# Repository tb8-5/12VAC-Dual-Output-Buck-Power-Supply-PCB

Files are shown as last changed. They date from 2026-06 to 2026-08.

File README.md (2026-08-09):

# 12VAC Dual-Output Buck Power Supply PCB

**Status:** Design Complete / Fabrication In Progress  
**Input:** 12 VAC RMS, 60 Hz  
**Outputs:** Fixed 5 V and 3.3 V rails  
**PCB:** 2-layer, 80.15 mm × 34.20 mm, 1.6 mm FR-4  
**Copper:** 35 µm top / 35 µm bottom  
**Revision:** Rev A  
**Design tools:** KiCad 9 and LTspice  

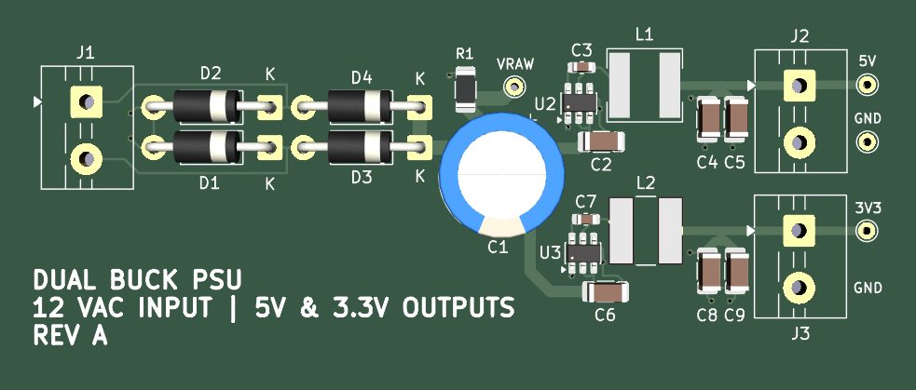
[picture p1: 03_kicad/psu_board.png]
3D render of the dual-output buck power supply PCB


## Overview

This project is a compact AC-to-DC power supply PCB that accepts **12 VAC** and produces two regulated DC outputs: **5 V** and **3.3 V**.

In simple terms, the board performs three jobs:

1. **Converts AC into DC** using a four-diode bridge rectifier.
2. **Smooths the rectified voltage** using a large bulk capacitor.
3. **Efficiently steps the DC voltage down** into separate 5 V and 3.3 V rails using two buck converters.

The project began with a linear-regulator architecture, but thermal calculations showed that too much power would be lost as heat. I redesigned the supply around two switching regulators and carried the design through schematic capture, component selection, footprint verification, PCB layout, routing, BOM preparation, and assembly-position-file generation.

The board has **not yet been fabricated or bench-tested**, so measured voltage, ripple, load-regulation, efficiency, and thermal results are intentionally left pending.

> **Input note:** This PCB is intended for a low-voltage 12 VAC source. It is not designed to connect directly to wall mains.

---

## Design Decision

### Original Linear-Regulator Approach

The first version used an **LM7805** to generate 5 V, followed by a second linear regulator for the 3.3 V rail.

LTspice rectifier simulation placed the filtered raw DC bus near **15.6 V**. At a 5 V, 1 A operating point, the LM7805 alone would dissipate:

```text
PLOSS = (VIN - VOUT) × IOUT

PLOSS = (15.6 V - 5 V) × 1 A
PLOSS = 10.6 W
```

A linear regulator removes excess voltage by turning it into heat. In this case, the regulator would be dissipating more than 10 W while only delivering 5 W to the load.

That made the linear architecture a poor fit for the size and thermal goals of the board.

### Buck-Converter Redesign

The supply was rebuilt around two fixed-output synchronous buck converters connected in parallel to the rectified DC bus:

- **U2 — AP63205WU-7:** fixed 5 V buck converter
- **U3 — AP63203WU-7:** fixed 3.3 V buck converter

A buck converter uses high-frequency switching, an inductor, and capacitors to transfer energy efficiently instead of continuously burning the voltage difference as heat.

The two output stages are **not cascaded**. Both converters receive power directly from `V_Raw`, so the 3.3 V rail does not depend on the 5 V regulator operating first.

---

## Final Architecture

```text
                         12 VAC INPUT
                              │
                              ▼
                 D1-D4: 1N4004 Bridge Rectifier
                              │
                              ▼
                 C1: 1000 µF Bulk Capacitor
                 R1: 10 kΩ Bleeder Resistor
                              │
                              ▼
                         V_RAW DC BUS
                              │
                 ┌────────────┴────────────┐
                 │                         │
                 ▼                         ▼
        5 V BUCK CONVERTER        3.3 V BUCK CONVERTER
            AP63205WU                 AP63203WU
                 │                         │
         C2: 10 µF input            C6: 10 µF input
         C3: 100 nF BST             C7: 100 nF BST
         L1: 4.7 µH                 L2: 3.9 µH
         C4/C5: 2 × 22 µF           C8/C9: 2 × 22 µF
                 │                         │
                 ▼                         ▼
           J2: 5 V / GND              J3: 3.3 V / GND
                 │                         │
             5 V test pad              3V3 test pad
```

Additional test access is provided for **VRAW** and **GND**.

---

## How the Circuit Works

### 1. AC Input and Full-Wave Rectification

`J1` accepts the 12 VAC input.

The four **1N4004** diodes (`D1-D4`) form a full-wave bridge rectifier. During each half-cycle of the AC waveform, a different pair of diodes conducts so that current through the DC side of the circuit always flows in the same direction.

For a 12 VAC RMS source, the unloaded sine-wave peak is approximately:

```text
VPEAK = VRMS × √2
VPEAK = 12 V × √2
VPEAK ≈ 16.97 V
```

The bridge introduces diode losses, so the usable rectified voltage is lower than the ideal peak. The LTspice work for this design produced a filtered raw bus near **15.6 V**.

Because both halves of the 60 Hz input waveform are used, the rectified ripple occurs at approximately **120 Hz**.

### 2. Bulk Filtering and VRAW

`C1` is a **1000 µF electrolytic capacitor** placed across the rectified output.

The bridge charges C1 near the peaks of the AC waveform. Between peaks, C1 supplies energy to the load and helps keep `V_Raw` from falling immediately back toward zero.

A first-order capacitor-ripple relationship is:

```text
ΔV ≈ ILOAD / (FRIPPLE × C)
```

where:

- `ΔV` is the approximate peak-to-peak bus ripple,
- `ILOAD` is the load current drawn from the rectified bus,
- `FRIPPLE` is approximately 120 Hz for 60 Hz full-wave rectification,
- `C` is the bulk capacitance.

`R1`, a **10 kΩ bleeder resistor**, provides a discharge path for the bulk capacitor after input power is removed. At approximately 15.6 V, it draws about **1.6 mA**, and the nominal `R × C` time constant is approximately **10 seconds**.

### 3. 5 V Buck Stage

The upper regulator stage uses `U2`, an **AP63205WU-7**, to generate the fixed 5 V rail.

Its external power-stage components are:

- `C2` — 10 µF local input capacitor
- `C3` — 100 nF bootstrap capacitor
- `L1` — 4.7 µH **TYS60284R7N-10**
- `C4`, `C5` — two 22 µF output capacitors

The switching node drives L1, and the inductor/output-capacitor network filters the switched waveform into a regulated DC output.

The finished 5 V rail is available at:

- `J2`
- the dedicated **5V** test pad

### 4. 3.3 V Buck Stage

The lower stage follows the same architecture using `U3`, an **AP63203WU-7**, for the fixed 3.3 V rail.

Its external components are:

- `C6` — 10 µF local input capacitor
- `C7` — 100 nF bootstrap capacitor
- `L2` — 3.9 µH **ASPI-0628-3R9M-T1**
- `C8`, `C9` — two 22 µF output capacitors

The finished 3.3 V rail is available at:

- `J3`
- the dedicated **3V3** test pad

---

## PCB Implementation

The final layout is a **2-layer board** measuring **80.15 mm × 34.20 mm**.

### Layer Stack

```text
Top Silkscreen
Top Solder Mask
35 µm F.Cu
1.51 mm FR-4 core
35 µm B.Cu
Bottom Solder Mask
Bottom Silkscreen
```

The complete PCB thickness is configured as **1.6 mm**.

### Layout Strategy

The board is organized left-to-right by power flow:

```text
12 VAC Input
    →
Bridge Rectifier
    →
Bulk Filtering / VRAW
    →
Parallel 5 V and 3.3 V Buck Stages
    →
Output Connectors
```

This physical organization makes the circuit easier to follow visually and keeps the functional blocks separated.

Other layout decisions include:

- **All populated assembly components are on the top side.**
- A **GND copper zone covers the bottom copper layer** to provide a low-impedance ground return.
- Wider traces are used on the main power paths, with routed widths reaching **1.25 mm** on portions of `V_Raw`.
- The regulated output routing uses wider sections up to approximately **0.75-1.0 mm**.
- Smaller **0.20 mm** traces are used where appropriate for lower-current local connections.
- The board includes plated test pads for `VRAW`, `5V`, `3V3`, and `GND`.
- The test pads are excluded from pick-and-place output because no separate test-point component needs to be assembled.
- `L1` uses a custom footprint matched to the **TYS60284R7N-10** land pattern.
- `L2` uses the custom **IND_ASPI-0628-3R9M-T1** footprint.
- Front silkscreen labels identify the input, both outputs, ground points, `VRAW`, and **REV A**.

---

## Test and Debug Access

Four dedicated plated test pads are included:

| Test pad | Purpose |
|---|---|
| `VRAW` | Measure the rectified and bulk-filtered DC bus |
| `5V` | Measure the regulated 5 V output |
| `3V3` | Measure the regulated 3.3 V output |
| `GND` | Oscilloscope / multimeter ground reference |

These pads are intended to make bring-up easier with a multimeter or oscilloscope without requiring probes to contact the small regulator pins directly.

---

## Bill of Materials

The current assembly BOM contains **11 unique line items and 21 populated components**:

- **13 SMD components**
- **8 through-hole components**
- **4 additional bare test-point pads** on the PCB

| Ref. | Qty. | Value / Function | Actual Part Number | Vendor Part # | Footprint |
|---|---:|---|---|---|---|
| C1 | 1 | 1000 µF bulk capacitor | `35PK1000MEFC10X20` | `C1580768` | `CP_Radial_D10.0mm_P5.00mm` |
| C2, C6 | 2 | 10 µF buck input capacitors | `CGA1206X5R106K350NT` | `C6119957` | `C_1206_3216Metric` |
| C3, C7 | 2 | 100 nF bootstrap capacitors | `C0603C104K5RACTU` | `C127833` | `C_0603_1608Metric` |
| C4, C5, C8, C9 | 4 | 22 µF output capacitors | `TMK316BBJ226ML-T` | `C386093` | `C_1206_3216Metric` |
| D1-D4 | 4 | 1N4004 bridge-rectifier diodes | `1N4004` | `C3058` | `D_DO-41_SOD81_P10.16mm_Horizontal` |
| J1-J3 | 3 | 2-position 5.0 mm terminal blocks | `MX126-5.0-02P-GN01-Cu-S-A` | `C5188434` | `TerminalBlock_MaiXu_MX126-5.0-02P_1x02_P5.00mm` |
| L1 | 1 | 4.7 µH 5 V buck inductor | `TYS60284R7N-10` | `C2454435` | `L_6.0x6.0_Pad1.8x5.7_Gap2.6` |
| L2 | 1 | 3.9 µH 3.3 V buck inductor | `ASPI-0628-3R9M-T1` | `C7325703` | `IND_ASPI-0628-3R9M-T1` |
| R1 | 1 | 10 kΩ VRAW bleeder resistor | `CRCW120610K0FKEA` | `C242483` | `R_1206_3216Metric` |
| U2 | 1 | Fixed 5 V synchronous buck | `AP63205WU-7` | `C2071056` | `TSOT-23-6` |
| U3 | 1 | Fixed 3.3 V synchronous buck | `AP63203WU-7` | `C780769` | `TSOT-23-6` |

The spreadsheet used for the current assembly quotation is included in the repository under `03_kicad`.

---

## KiCad / Manufacturing Files

The `03_kicad` directory contains the current source and assembly-support files:

```text
03_kicad/
├── screenshots/
├── psu_board.png
├── psu_bom(2026-08-06).xlsx
├── psu_main.kicad_pcb
├── psu_main.kicad_pro
├── psu_main.kicad_sch
├── psu_main-top.pos
└── psu_main-bottom.pos
```

Useful direct links:

- [KiCad schematic](03_kicad/psu_main.kicad_sch)
- [KiCad PCB layout](03_kicad/psu_main.kicad_pcb)
- [KiCad project file](03_kicad/psu_main.kicad_pro)
- [Assembly BOM](03_kicad/psu_bom%282026-08-06%29.xlsx)
- [Top-side component positions](03_kicad/psu_main-top.pos)
- [Bottom-side component positions](03_kicad/psu_main-bottom.pos)

The top-side position file contains all 21 populated BOM components. The bottom-side position file is intentionally empty because no assembly components are mounted on the bottom of the PCB.

---

## Current Validation Status

### Completed

- Initial linear-regulator thermal analysis
- LTspice bridge-rectifier / bulk-filter simulation
- Buck-converter architecture redesign
- Component selection
- Schematic capture
- Footprint assignment and verification
- Custom inductor footprint integration
- 2-layer PCB placement and routing
- Bottom-layer GND plane
- Input / output / VRAW test access
- BOM generation and assembly part matching
- Top and bottom component-position-file generation
- Fabrication package review

### Pending - Board Review

The board has not yet been physically validated. Bench testing will include:

1. Visual inspection and continuity checks before power-up
2. `VRAW` DC level and 120 Hz ripple measurement
3. 5 V output-voltage verification
4. 3.3 V output-voltage verification
5. Output ripple measurement with an oscilloscope
6. Load-regulation testing
7. Regulator and inductor thermal checks under load
8. Comparison of measured results against the calculated and simulated behavior

No measured hardware results are reported in this repository until the fabricated board has been assembled and tested.

---

## Project Goal

The goal of this project was not only to create two DC rails, but to work through the complete hardware-design process:

```text
Requirements
    →
Architecture Selection
    →
Calculation / Simulation
    →
Component Selection
    →
Schematic Capture
    →
Footprint Verification
    →
PCB Layout and Routing
    →
Manufacturing Documentation
    →
Fabrication
    →
Bench Validation
```

The largest design change came from recognizing that the original linear-regulator architecture created an unacceptable thermal problem and then redesigning the system around switching regulators before committing the PCB to fabrication.

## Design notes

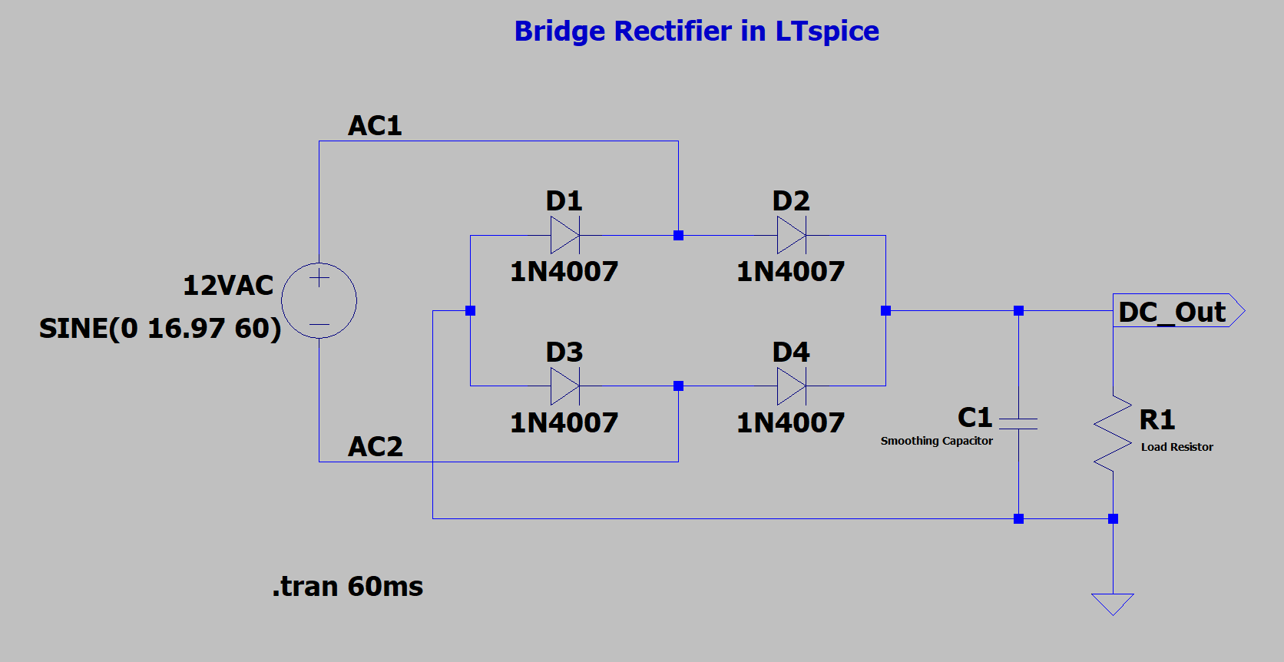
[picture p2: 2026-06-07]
02_ltspice/screenshots/schematic.png

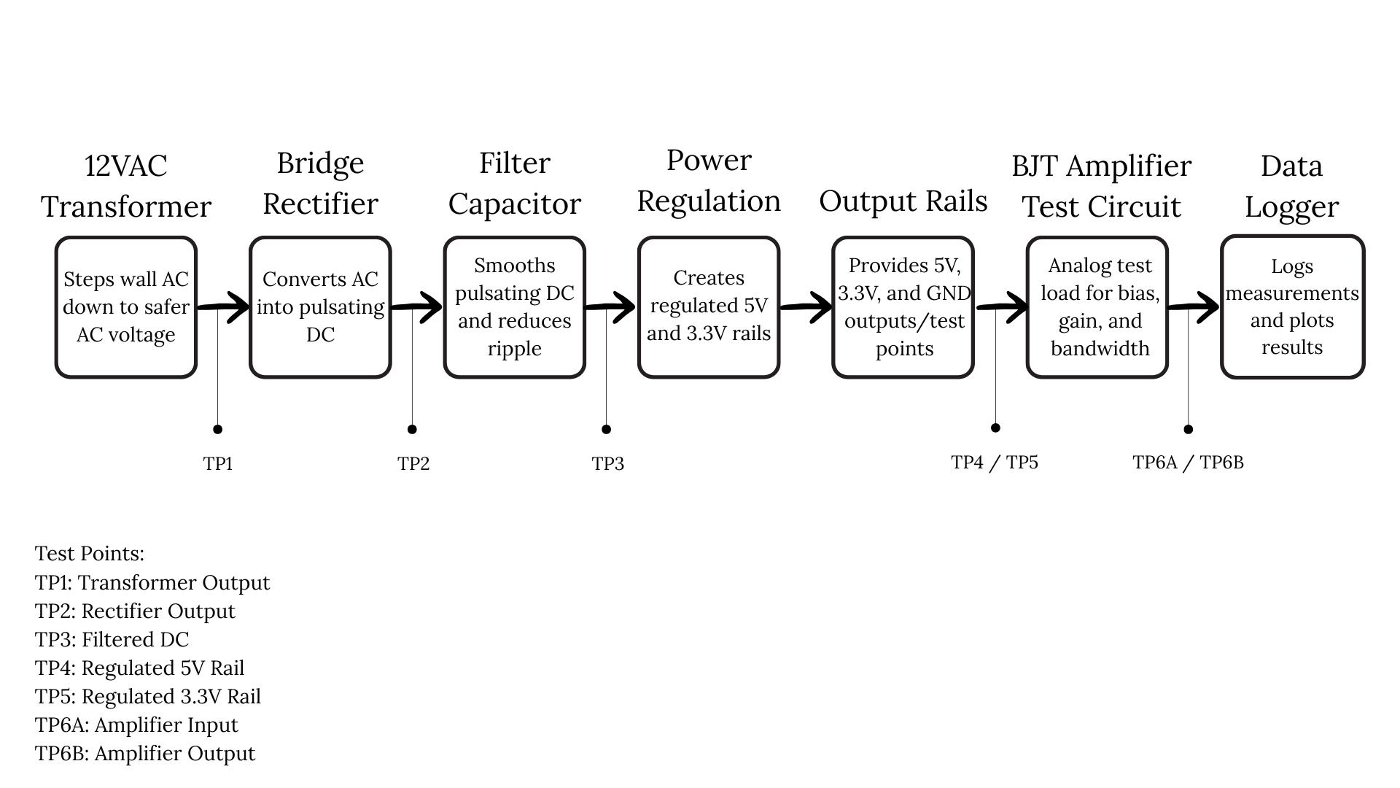
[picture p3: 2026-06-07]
01_docs/original_layout_design.jpg

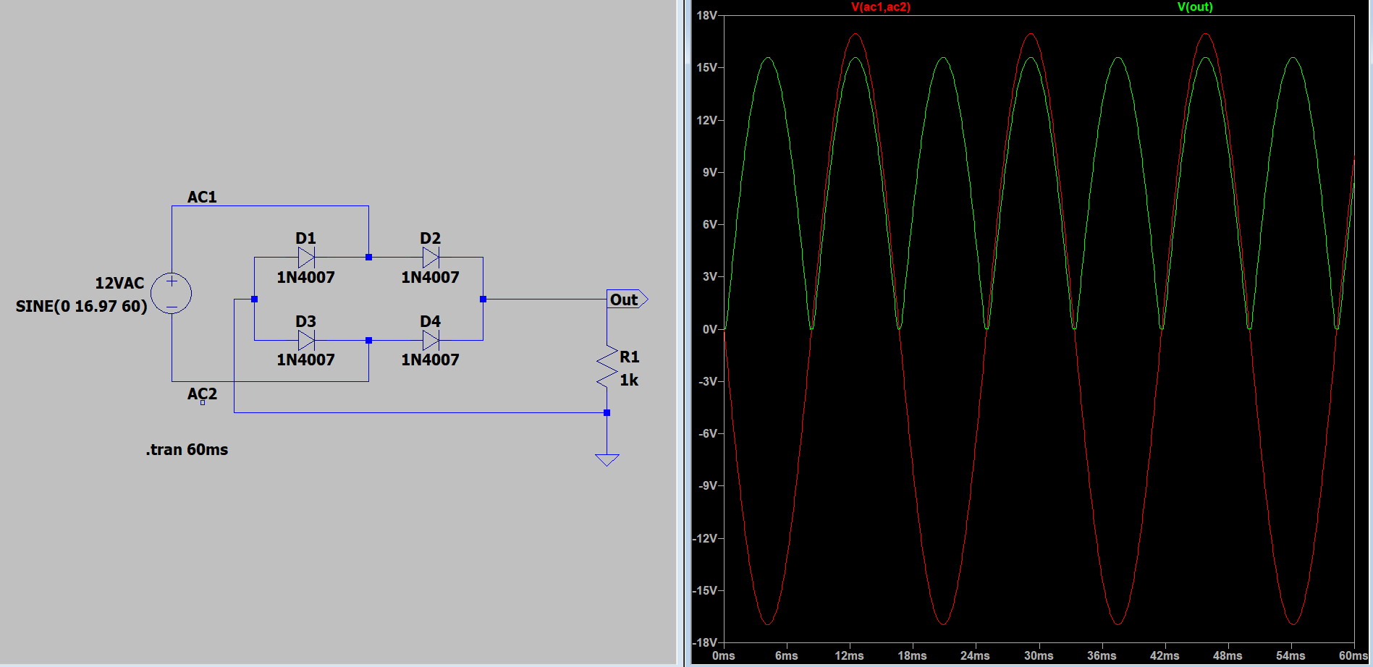
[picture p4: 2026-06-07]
02_ltspice/screenshots/t1_fwr_no_cap_1k_res.png

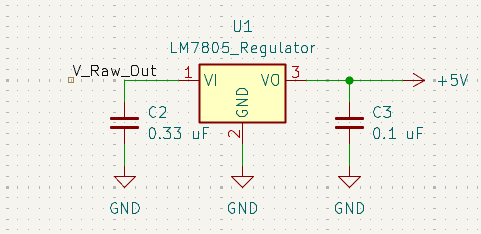
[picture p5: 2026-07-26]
03_kicad/screenshots/lm_reg.png

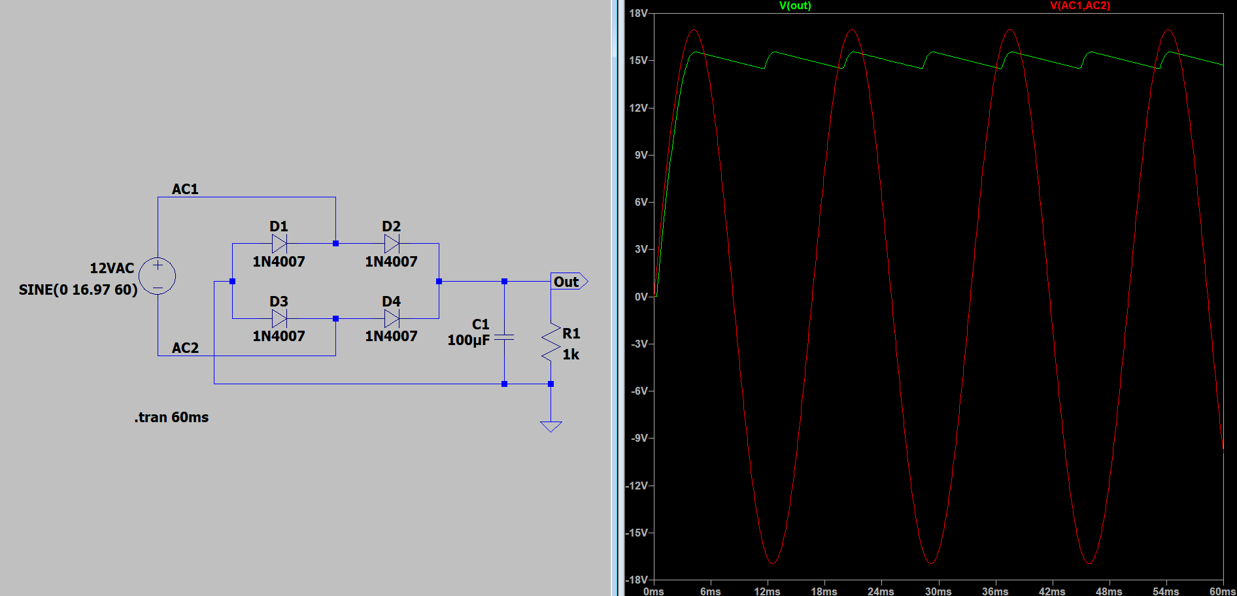
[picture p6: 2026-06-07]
02_ltspice/screenshots/t2_fwr_100uf_cap_1k_res.png

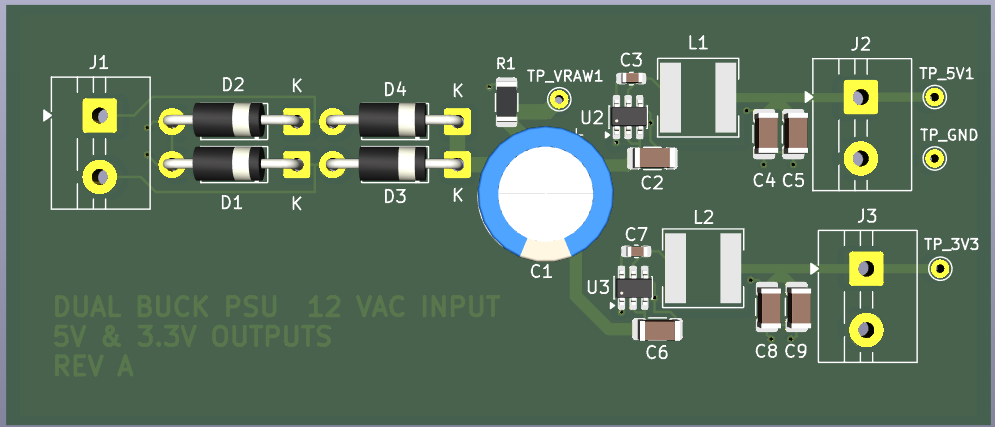
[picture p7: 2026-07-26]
03_kicad/screenshots/psu_main_scrshot.png

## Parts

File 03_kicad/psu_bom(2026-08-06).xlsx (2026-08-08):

PCBWay Bom Quotation, Product No.:T-1C2W1121237A
Item # | *Designator | *Qty | *Mfg Part # | Description / Value | Vendor Part # | *Package/Footprint | *Unit Price(5 units) | *Total | *Delivery Time | *Actual Purchase Mfg Part # | Customer Reply | PCBWay Update
1 | C1 | 1 | C1580768 | 1000uF | C1580768 | Capacitor_THT:CP_Radial_D10.0mm_P5.00mm | $1.445 | $7.225 |  | 35PK1000MEFC10X20
2 | C2,C6 | 2 | C6119957 | 10uF | C6119957 | Capacitor_SMD:C_1206_3216Metric | $0.514 | $5.140 |  | CGA1206X5R106K350NT
3 | C3,C7 | 2 | C127833 | 100nF | C127833 | Capacitor_SMD:C_0603_1608Metric | $0.172 | $1.720 |  | C0603C104K5RACTU
4 | C4,C5,C8,C9 | 4 | C386093 | 22uF | C386093 | Capacitor_SMD:C_1206_3216Metric | $0.788 | $15.760 |  | TMK316BBJ226ML-T
5 | D1,D2,D3,D4 | 4 | C3058 | 1N4004 | C3058 | Diode_THT:D_DO-41_SOD81_P10.16mm_Horizontal | $0.048 | $0.960 |  | 1N4004
6 | J1, J2, J3 | 3 | C5188434 | 12VAC IN | C5188434 | TerminalBlock:TerminalBlock_MaiXu_MX126-5.0-02P_1x02_P5.00mm | $0.114 | $1.710 |  | MX126-5.0-02P-GN01-Cu-S-A
7 | L1 | 1 | C2454435 | 4.7uH | C2454435 | Custom_Footprints:L_6.0x6.0_Pad1.8x5.7_Gap2.6 | $0.963 | $4.815 | 7-10 Workdays | TYS60284R7N-10
8 | L2 | 1 | C7325703 | 3.9uH | C7325703 | Custom_Footprints:IND_ASPI-0628-3R9M-T1 | $0.645 | $3.225 |  | ASPI-0628-3R9M-T1
9 | R1 | 1 | C242483 | 10k | C242483 | Resistor_SMD:R_1206_3216Metric | $0.235 | $1.175 |  | CRCW120610K0FKEA
10 | U2 | 1 | C2071056 | AP63205WU | C2071056 | Package_TO_SOT_SMD:TSOT-23-6 | $0.702 | $3.510 |  | AP63205WU-7
11 | U3 | 1 | C780769 | AP63203WU | C780769 | Package_TO_SOT_SMD:TSOT-23-6 | $2.319 | $11.595 | 7-10 Workdays | AP63203WU-7
 |  |  |  |  |  |  | Component Cost | $56.83
 |  |  |  |  |  |  | Assembly Cost | $29.00
 |  |  |  |  |  |  | PCB Cost | $6.50
 |  |  |  |  |  |  | V0 Member 0% off | $0.00
 |  |  |  |  |  |  | All Total 5 Units | $92.33

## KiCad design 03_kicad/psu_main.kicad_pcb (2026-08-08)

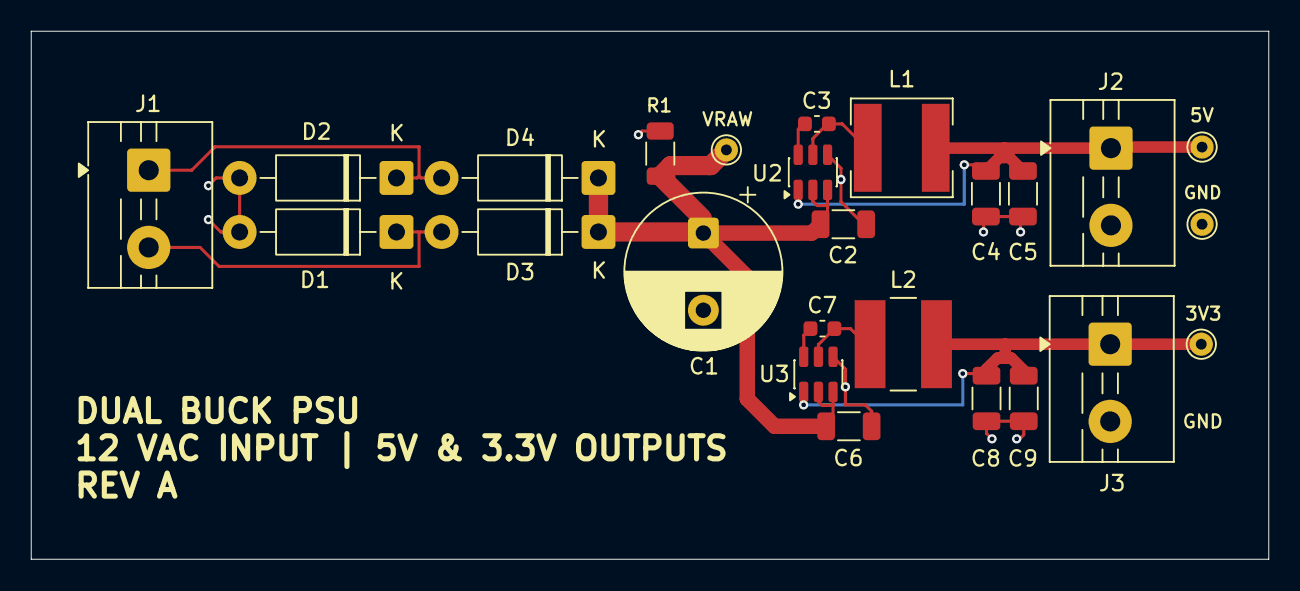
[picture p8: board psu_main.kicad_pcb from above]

Board: 2 copper layers, 80.2 x 34.2 mm, 25 parts (0 on the bottom side), 10 nets.

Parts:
3V3: 3V3_Out; TestPoint_THTPad_D1.5mm_Drill0.7mm
5V: 5V_Out; TestPoint_THTPad_D1.5mm_Drill0.7mm
C1: 1000uF; CP_Radial_D10.0mm_P5.00mm
C2, C6: 10uF; C_1206_3216Metric
C3, C7: 100nF; C_0603_1608Metric
C4, C5, C8, C9: 22uF; C_1206_3216Metric
D1, D2, D3, D4: 1N4004; D_DO-41_SOD81_P10.16mm_Horizontal
GND: TestPoint; TestPoint_THTPad_D1.5mm_Drill0.7mm
J1: 12VAC IN; TerminalBlock_MaiXu_MX126-5.0-02P_1x02_P5.00mm
J2: 5V_Out; TerminalBlock_MaiXu_MX126-5.0-02P_1x02_P5.00mm
J3: 3V3_Out; TerminalBlock_MaiXu_MX126-5.0-02P_1x02_P5.00mm
L1: 4.7uH; L_6.0x6.0_Pad1.8x5.7_Gap2.6
L2: 3.9uH; IND_ASPI-0628-3R9M-T1
R1: 10k; R_1206_3216Metric
U2: AP63205WU; TSOT-23-6
U3: AP63203WU; TSOT-23-6
VRAW: TestPoint; TestPoint_THTPad_D1.5mm_Drill0.7mm

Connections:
/3V3_Out: 3V3.1, C8.1, C9.1, J3.1, L2.2, U3.1 (FB)
/5V_Out: 5V.1, C4.1, C5.1, J2.1, L1.2, U2.1 (FB)
/V_Raw: C1.1, C2.1, C6.1, D3.1 (K), D4.1 (K), R1.1, U2.2 (EN), U2.3 (IN), U3.2 (EN), U3.3 (IN), VRAW.1
GND: C1.2, C2.2, C4.2, C5.2, C6.2, C8.2, C9.2, D1.2 (A), D2.2 (A), GND.1, J2.2, J3.2, R1.2, U2.4 (GND), U3.4 (GND)
unnamed: D1.1 (K), D3.2 (A), J1.2
unnamed: D2.1 (K), D4.2 (A), J1.1
unnamed: C3.2, U2.6 (BST)
unnamed: C3.1, L1.1, U2.5 (SW)
unnamed: C7.2, U3.6 (BST)
unnamed: C7.1, L2.1, U3.5 (SW)

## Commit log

2026-06-07 Revise README with project details and status
    Updated project overview, goals, current status, simulation details, and planned features for the custom PSU PCB and analog characterization platform.
2026-08-03 Italicize PCB design change note in README
    Updated PCB note to italicize subject to design changes.
2026-08-03 Clarify PCB specifications in README
    Removed note about subject to design changes for PCB.
